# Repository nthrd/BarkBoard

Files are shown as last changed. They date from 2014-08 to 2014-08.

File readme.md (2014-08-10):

BarkBoard for BeagleBone Black
==============================

Overview
--------
The BarkBoard is concept for a DSP and modular amplifier cape for the BeagleBone and BeagleBone Black. Leveraging an digital signal processor, a high powered ADC/DAC, radio tuner and optional bluetooth audio module in addition to the digital audio output of the BeagleBone, the BarkBoard will makes any custom audio solution simple to build. A modular connector board will provide the ability to interface with a variety of audio systems, such as OEM car stereo plugs, musical instruments or home theater systems. Individual ready-made or custom amplifier boards will allow you to determine how much power you want to put into each channel depending on your application.

Form Factor
-----------

The BarkBoard is designed to fit inside a standard double-DIN enclosure used for many car-stereos. Add a GPS cape to this board and a car-navigation system is at your fingerprints. The modular connector board and amplifier boards are designed to be rear facing and are adaptable to a variety of audio systems. Some ideas include:
*  Custom Android or Linux Car-Stereo
*  Custom Audio player
*  Guitar amplifier with digital effects and the ability to mix other instruments.
*  Home Theater system

Digital Signal Processing
-------------------------

The power of the on board DSP combined with the ability to fully program the algorithms available on the board make the bark board a very versatile solution. Write your own algorithms or select from a variety of existing plugins to modify the digital audio signals as they flow from one source to another on the board, creating a custom sound tailored to your application. With the ability to load and configure software at boot or while running via the BeagleBoard's I2C, here are just a few ways you might utilize this chip.
Mix digital Audio Signals
*  Equalization
*  Tone Control
*  Bass Boost
*  Custom Effects
*  Custom Connector Board

The modular connector board can be used in many situations. Use a phono jack to plug in your guitar or 3D print a connector to mimic your OEM car stereo. The board will come with an one of the following (as an option):
Basic Audio connection: Speaker terminals for output and 2.5mm jacks for line in and mic in.
Home Theater: RCA jacks for all 6 audio output channels, S/PDIF in/out, 2.5mm jack for line in.
Protoboard: Positioned and labeled headers with a bunch of holes for prototyping your custom connection.
Custom Amplifier Boards

Each amplifier board is supplied with the differential analog output from the DAC, two control pins connected to an ATMEGA 328, which can be controlled via I2C from using the beagleboard a +12V supply and a +3.3V supply. One of the control pins on each board is connected to the 328's PWM pin and can be used as an analog control. The output pins connect straight through to the connector board. Off-the-shelf options for this board may include:
*  Protoboard: Positioned and labeled headers with a bunch of holes for prototyping your custom amplifier.
*  Pass-through Board: Pass the outputs of the DAC straight to the connection board.
*  1W/channel amplifier board
*  10W/channel amplifier board

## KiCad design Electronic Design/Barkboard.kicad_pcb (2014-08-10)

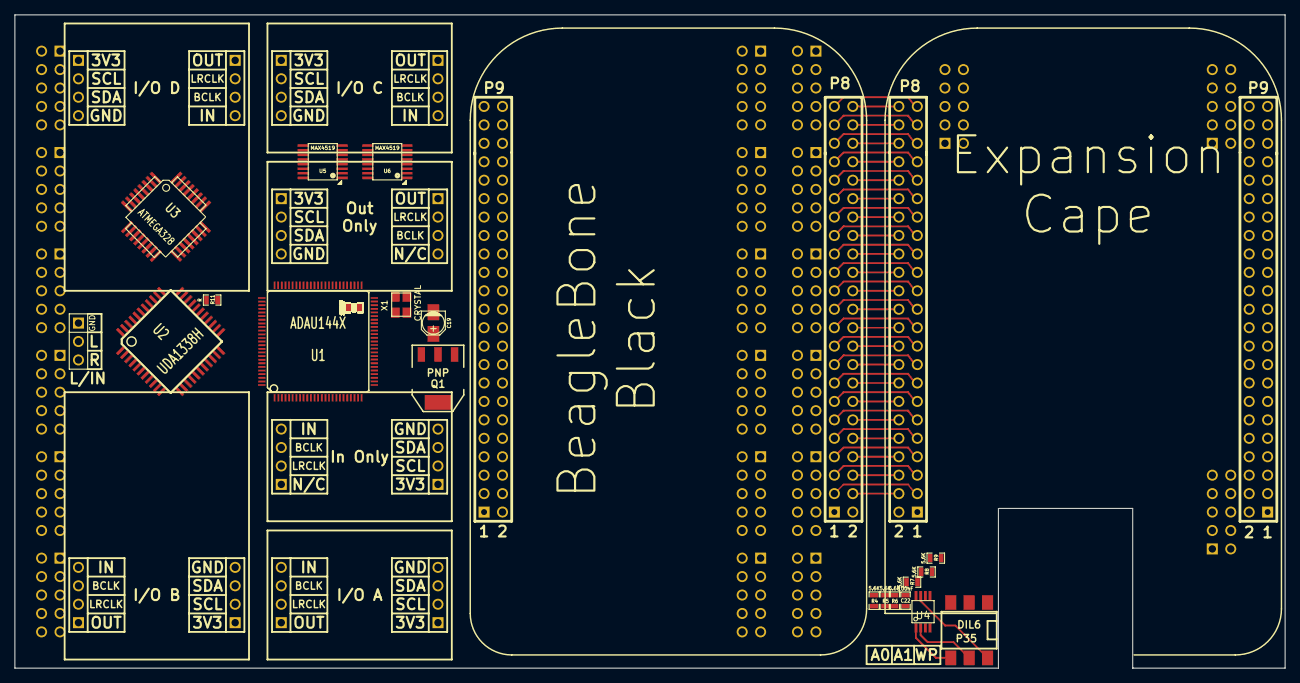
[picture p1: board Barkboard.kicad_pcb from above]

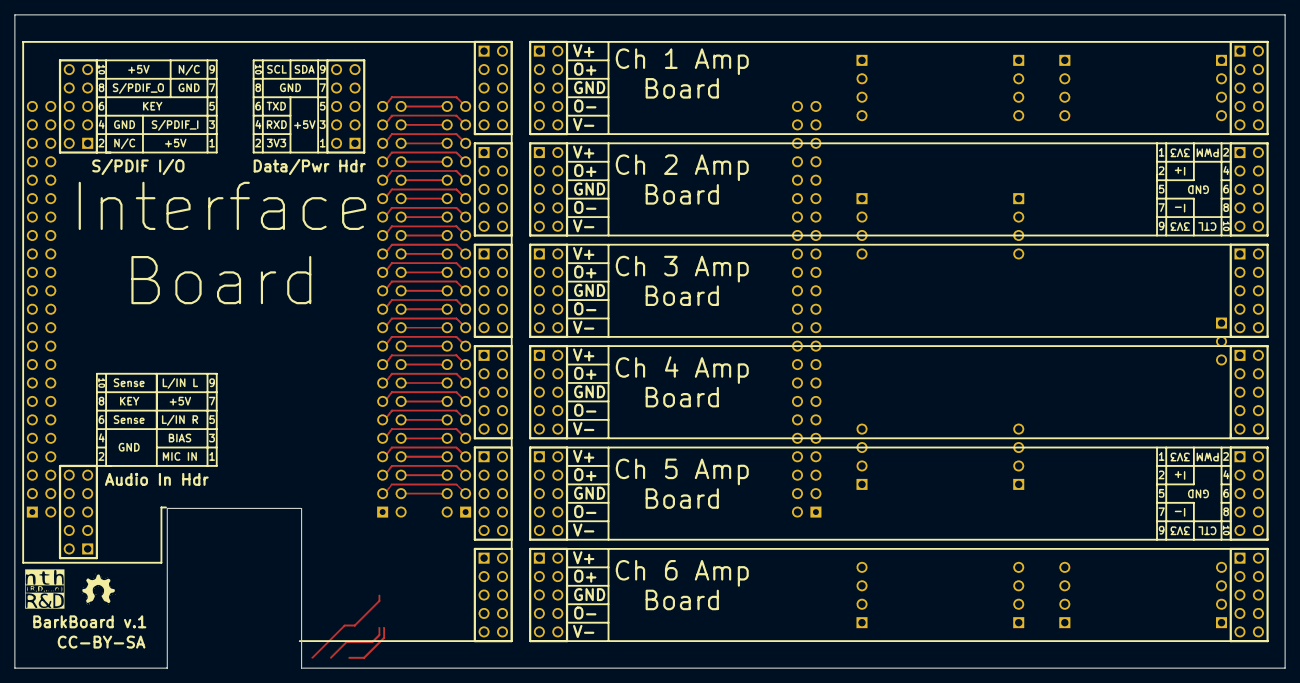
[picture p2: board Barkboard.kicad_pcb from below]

Board: 4 copper layers, 175.0 x 90.0 mm, 79 parts (21 on the bottom side), 197 nets.

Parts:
C1: 33nF; SM0603_Capa
C2: 1.8nF; SM0603_Capa
C3, C4, C5, C6, C7, C8, C9, C10, C11, C12, C13, C14, C15, C16, C17, C18, C22: 100nF; SM0603_Capa
C19: 10uF; c_elec_3x5.3
C20, C21: 22pF; SM0603_Capa
P1: Bone_P8; BONE_HDR_FLIP
P2: Bone_P9; BONE_HDR_FLIP
P3: Cape_P8; PIN_ARRAY_23X2
P4: Cape_P9; PIN_ARRAY_23X2
P5, P6, P7, P8, P9, P10, P11, P12, P13, P14, P15, P16, P21, P22, P23, P24, P25, P26, P36, P37, P38: CONN_5X2; PIN_ARRAY_5x2
P17: IODA; PIN_ARRAY_4x1
P18: IOPA; PIN_ARRAY_4x1
P19: IODB; PIN_ARRAY_4x1
P20: IOPB; PIN_ARRAY_4x1
P27: IODC; PIN_ARRAY_4x1
P28: IOPC; PIN_ARRAY_4x1
P29: IODD; PIN_ARRAY_4x1
P30: IOPD; PIN_ARRAY_4x1
P31: IP; PIN_ARRAY_4x1
P32: ID; PIN_ARRAY_4x1
P33: OP; PIN_ARRAY_4x1
P34: OD; PIN_ARRAY_4x1
P35: DIL6; 6DIPCMS
P39: CONN_3; PIN_ARRAY_3X1
Q1: PNP; SOT223
R1: 1.5K; SM0603_Resistor
R2: 10K; SM0603_Resistor
R3: 100; SM0603_Resistor
R4, R5, R6, R7, R8, R9: 5.6K; SM0603_Resistor
R11: R; SM0603_Resistor
U1: ADAU144X; TQFP_100
U2: UDA1338H; TQFP44
U3: ATMEGA328; TQFP32
U4: 24C256; SSOP8
U5, U6: MAX4519; qsop-16
X1: CRYSTAL; crystal_FA238-TSX3225

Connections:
3V3: C2.1, C3.1, C5.1, C6.1, C8.1, C10.1, C11.1, C13.1, C14.1, C16.1, C18.1, P18.1, P20.1, P21.1, P21.9, P22.1, P22.9, P23.1, P23.9, P24.1, P24.9, P25.1, P25.9, P26.1, P26.9, P28.1, P30.1, P31.1, P33.1, P38.2, Q1.1, R1.1, R11.1, U1.2, U1.14, U1.27, U1.39, U1.44, U1.49, U1.52, U1.63, U1.77, U1.89, U2.5, U2.9, U2.29, U2.37, U5.2, U5.14, U6.2, U6.14
+1.8V: C4.1, C7.1, C9.1, C12.1, C15.1, C17.1, C19.1, Q1.3, U1.25, U1.37, U1.50, U1.75, U1.87, U1.100
+5V: P2.5, P2.6, P4.5, P4.6, P36.1, P36.10, P37.7, P38.1, P38.3, P38.5
/AD1: U1.5, U2.13
/AD2: U1.8, U2.12
/ADBC: U1.9, U2.14
/ADLR: U1.10, U2.15
/ADV: U1.11, U2.16
/ADVBC: U1.12, U2.17
/ADVLR: U1.15, U2.18
/AD_RESET: U1.54, U3.23
/AT_RX: U3.30, U5.10, U6.4
/AT_TX: U3.31, U5.4, U6.10
/Amplifier and Interface Connectors/C1_CTL: P21.10, U3.32
/Amplifier and Interface Connectors/C1_I+: P21.3, U2.31
/Amplifier and Interface Connectors/C1_I-: P21.7, U2.32
/Amplifier and Interface Connectors/C1_O+: P5.3, P5.4, P11.3, P11.4
/Amplifier and Interface Connectors/C1_O-: P5.7, P5.8, P11.7, P11.8
/Amplifier and Interface Connectors/C1_PWM: P21.2, U3.1
/Amplifier and Interface Connectors/C1_V+: P5.1, P5.2, P11.1, P11.2
/Amplifier and Interface Connectors/C1_V-: P5.9, P5.10, P11.9, P11.10
/Amplifier and Interface Connectors/C2_CTL: P22.10, U3.2
/Amplifier and Interface Connectors/C2_I+: P22.3, U2.33
/Amplifier and Interface Connectors/C2_I-: P22.7, U2.34
/Amplifier and Interface Connectors/C2_O+: P6.3, P6.4, P12.3, P12.4
/Amplifier and Interface Connectors/C2_O-: P6.7, P6.8, P12.7, P12.8
/Amplifier and Interface Connectors/C2_PWM: P22.2, U3.9
/Amplifier and Interface Connectors/C2_V+: P6.1, P6.2, P12.1, P12.2
/Amplifier and Interface Connectors/C2_V-: P6.9, P6.10, P12.9, P12.10
/Amplifier and Interface Connectors/C3_CTL: P23.10, U3.11
/Amplifier and Interface Connectors/C3_I+: P23.3, U2.35
/Amplifier and Interface Connectors/C3_I-: P23.7, U2.36
/Amplifier and Interface Connectors/C3_O+: P7.3, P7.4, P13.3, P13.4
/Amplifier and Interface Connectors/C3_O-: P7.7, P7.8, P13.7, P13.8
/Amplifier and Interface Connectors/C3_PWM: P23.2, U3.10
/Amplifier and Interface Connectors/C3_V+: P7.1, P7.2, P13.1, P13.2
/Amplifier and Interface Connectors/C3_V-: P7.9, P7.10, P13.9, P13.10
/Amplifier and Interface Connectors/C4_CTL: P24.10, U3.12
/Amplifier and Interface Connectors/C4_I+: P24.3, U2.38
/Amplifier and Interface Connectors/C4_I-: P24.7, U2.39
/Amplifier and Interface Connectors/C4_O+: P8.3, P8.4, P14.3, P14.4
/Amplifier and Interface Connectors/C4_O-: P8.7, P8.8, P14.7, P14.8
/Amplifier and Interface Connectors/C4_PWM: P24.2, U3.13
/Amplifier and Interface Connectors/C4_V+: P8.1, P8.2, P14.1, P14.2
/Amplifier and Interface Connectors/C4_V-: P8.9, P8.10, P14.9, P14.10
/Amplifier and Interface Connectors/C5_CTL: P25.10, U3.16
/Amplifier and Interface Connectors/C5_I+: P25.3, U2.41
/Amplifier and Interface Connectors/C5_I-: P25.7, U2.42
/Amplifier and Interface Connectors/C5_O+: P9.3, P9.4, P15.3, P15.4
/Amplifier and Interface Connectors/C5_O-: P9.7, P9.8, P15.7, P15.8
/Amplifier and Interface Connectors/C5_PWM: P25.2, U3.14
/Amplifier and Interface Connectors/C5_V+: P9.1, P9.2, P15.1, P15.2
/Amplifier and Interface Connectors/C5_V-: P9.9, P9.10, P15.9, P15.10
/Amplifier and Interface Connectors/C6_CTL: P26.10, U3.17
/Amplifier and Interface Connectors/C6_I+: P26.3, U2.43
/Amplifier and Interface Connectors/C6_I-: P26.7, U2.44
/Amplifier and Interface Connectors/C6_O+: P10.3, P10.4, P16.3, P16.4
/Amplifier and Interface Connectors/C6_O-: P10.7, P10.8, P16.7, P16.8
/Amplifier and Interface Connectors/C6_PWM: P26.2, U3.15
/Amplifier and Interface Connectors/C6_V+: P10.1, P10.2, P16.1, P16.2
/Amplifier and Interface Connectors/C6_V-: P10.9, P10.10, P16.9, P16.10
/Amplifier and Interface Connectors/LineIn_L: P37.9, U2.6
/Amplifier and Interface Connectors/LineIn_R: P37.5, U2.8
/Amplifier and Interface Connectors/MIC: P37.1, U2.10
/Amplifier and Interface Connectors/SPDIF_IN: P36.3, U1.46
/Amplifier and Interface Connectors/SPDIF_OUT: P36.8, U1.47
/Amplifier and Interface Connectors/UART_RX: P38.4, U6.11
/Amplifier and Interface Connectors/UART_TX: P38.6, U5.11
/BeagleBone and Cape/3V3_exp: C22.1, P2.3, P2.4, P4.3, P4.4, R4.1, R5.1, R6.1, R7.1, R8.1, R9.1, U4.8
/BeagleBone and Cape/5V_SYS: P2.7, P2.8, P4.7, P4.8
/BeagleBone and Cape/AIN0: P2.39, P4.39
/BeagleBone and Cape/AIN1: P2.40, P4.40
/BeagleBone and Cape/AIN2: P2.37, P4.37
/BeagleBone and Cape/AIN3: P2.38, P4.38
/BeagleBone and Cape/AIN4: P2.33, P4.33
/BeagleBone and Cape/AIN5: P2.36, P4.36
/BeagleBone and Cape/AIN6: P2.35, P4.35
/BeagleBone and Cape/CLKOUT2: P2.41, P4.41
/BeagleBone and Cape/EHRPWM1A: P2.14, P4.14
/BeagleBone and Cape/EHRPWM1B: P2.16, P4.16
/BeagleBone and Cape/EHRPWM2A: P1.19, P3.19
/BeagleBone and Cape/EHRPWM2B: P1.13, P3.13
/BeagleBone and Cape/GNDA_ADC: P2.34, P4.34
/BeagleBone and Cape/GPIO0_7: P2.42, P4.42
/BeagleBone and Cape/GPIO0_26: P1.14, P3.14
/BeagleBone and Cape/GPIO1_0: P1.25, P3.25
/BeagleBone and Cape/GPIO1_1: P1.24, P3.24
/BeagleBone and Cape/GPIO1_2: P1.5, P3.5
/BeagleBone and Cape/GPIO1_3: P1.6, P3.6
/BeagleBone and Cape/GPIO1_4: P1.23, P3.23
/BeagleBone and Cape/GPIO1_5: P1.22, P3.22
/BeagleBone and Cape/GPIO1_6: P1.3, P3.3
/BeagleBone and Cape/GPIO1_7: P1.4, P3.4
/BeagleBone and Cape/GPIO1_12: P1.12, P3.12
/BeagleBone and Cape/GPIO1_13: P1.11, P3.11
/BeagleBone and Cape/GPIO1_14: P1.16, P3.16
/BeagleBone and Cape/GPIO1_15: P1.15, P3.15
/BeagleBone and Cape/GPIO1_16: P2.15, P4.15
/BeagleBone and Cape/GPIO1_17: P2.23, P4.23
/BeagleBone and Cape/GPIO1_27: P1.17, P3.17
/BeagleBone and Cape/GPIO1_28: P2.12, P4.12
/BeagleBone and Cape/GPIO1_29: P1.26, P3.26
/BeagleBone and Cape/GPIO1_30: P1.21, P3.21
/BeagleBone and Cape/GPIO1_31: P1.20, P3.20
/BeagleBone and Cape/GPIO2_1: P1.18, P3.18
/BeagleBone and Cape/GPIO2_6: P1.45, P3.45
/BeagleBone and Cape/GPIO2_7: P1.46, P3.46
/BeagleBone and Cape/GPIO2_8: P1.43, P3.43
/BeagleBone and Cape/GPIO2_9: P1.44, P3.44
/BeagleBone and Cape/GPIO2_10: P1.41, P3.41
/BeagleBone and Cape/GPIO2_11: P1.42, P3.42
/BeagleBone and Cape/GPIO2_12: P1.39, P3.39
/BeagleBone and Cape/GPIO2_13: P1.40, P3.40
/BeagleBone and Cape/GPIO2_22: P1.27, P3.27
/BeagleBone and Cape/GPIO2_23: P1.29, P3.29
/BeagleBone and Cape/GPIO2_24: P1.28, P3.28
/BeagleBone and Cape/GPIO2_25: P1.30, P3.30
/BeagleBone and Cape/GPIO3_19: P2.27, U1.90
/BeagleBone and Cape/GPIO3_21: P2.25, P4.25
/BeagleBone and Cape/ID_ADD0: P35.4, R4.2, U4.1
/BeagleBone and Cape/ID_ADD1: P35.5, R5.2, U4.2
/BeagleBone and Cape/ID_SCL: P2.19, P4.19, R8.2, U4.6
/BeagleBone and Cape/ID_SDA: P2.20, P4.20, R9.2, U4.5
/BeagleBone and Cape/PWR_BUT: P2.9, P4.9
/BeagleBone and Cape/SPI1_CS: P2.28, U1.84
/BeagleBone and Cape/SPI1_D0: P2.29, U1.86
/BeagleBone and Cape/SPI1_D1: P2.30, P4.30
/BeagleBone and Cape/SPI1_SCLK: P2.31, U1.85
/BeagleBone and Cape/SYS_RESETn: P2.10, P4.10
/BeagleBone and Cape/TIEMR5: P1.9, P3.9
/BeagleBone and Cape/TIMER4: P1.7, P3.7
/BeagleBone and Cape/TIMER6: P1.10, P3.10
/BeagleBone and Cape/TIMER7: P1.8, P3.8
/BeagleBone and Cape/UART1_RXD: P2.26, P4.26, U6.5
/BeagleBone and Cape/UART1_TXD: P2.24, P4.24, U5.5
/BeagleBone and Cape/UART2_RXD: P2.22, P4.22
/BeagleBone and Cape/UART2_TXD: P2.21, P4.21
/BeagleBone and Cape/UART3_CTSN: P1.36, P3.36
/BeagleBone and Cape/UART3_RTSN: P1.34, P3.34
/BeagleBone and Cape/UART4_CTSN: P1.35, P3.35
/BeagleBone and Cape/UART4_RTSN: P1.33, P3.33
/BeagleBone and Cape/UART4_RXD: P2.11, P4.11
/BeagleBone and Cape/UART4_TXD: P2.13, P4.13
/BeagleBone and Cape/UART5_CTSN: P1.31, P3.31
/BeagleBone and Cape/UART5_RTSN: P1.32, P3.32
/BeagleBone and Cape/UART5_RXD: P1.38, P3.38
/BeagleBone and Cape/UART5_TXD: P1.37, P3.37
/BeagleBone and Cape/VDD_ADC: P2.32, P4.32
/BeagleBone and Cape/WP: P35.6, R7.2, U4.7
/DA12: U1.69, U2.25
/DA34: U1.66, U2.26
/DA56: U1.61, U2.27
/DABC: U1.64, U2.24
/DALR: U1.65, U2.23
/IBC: P32.3, U1.3
/II: P32.4, U1.99
/ILR: P32.2, U1.4
/IOABC: P17.3, U1.96
/IOAI: P17.4, U1.95
/IOALR: P17.2, U1.97
/IOAO: P17.1, U1.98
/IOBBC: P19.3, U1.92
/IOBI: P19.4, U1.91
/IOBLR: P19.2, U1.93
/IOBO: P19.1, U1.94
/IOCBC: P27.3, U1.74
/IOCI: P27.4, U1.73
/IOCLR: P27.2, U1.78
/IOCO: P27.1, U1.79
/IODBC: P29.3, U1.81
/IODI: P29.4, U1.80
/IODLR: P29.2, U1.82
/IODO: P29.1, U1.83
/MP8: U1.19, U5.1, U6.1
/MP9: U1.18, U5.16, U6.16
/MP10: U1.17, U3.29
/MP11: U1.16, U2.20
/MSTR_CLK: U1.53, U2.19
/OBC: P34.3, U1.70
/OLR: P34.2, U1.71
/OO: P34.1, U1.72
/PFILT: C1.2, C2.2, U1.43
/VDRIVE: Q1.2, U1.40
/XI: C20.1, U1.42, X1.2
/XO1: R3.1, U1.41
/XO2: C21.1, R3.2, X1.1
GND: C3.2, C4.2, C5.2, C6.2, C7.2, C8.2, C9.2, C10.2, C11.2, C12.2, C13.2, C14.2, C15.2, C16.2, C17.2, C18.2, C19.2, C20.2, C21.2, C22.2, P1.1, P1.2, P2.1, P2.2, P2.43, P2.44, P2.45, P2.46, P3.1, P3.2, P4.1, P4.2, P4.43, P4.44, P4.45, P4.46, P5.5, P5.6, P6.5, P6.6, P7.5, P7.6, P8.5, P8.6, P9.5, P9.6, P10.5, P10.6, P11.5, P11.6, P12.5, P12.6, P13.5, P13.6, P14.5, P14.6, P15.5, P15.6, P16.5, P16.6, P18.4, P20.4, P21.4, P21.5, P21.6, P21.8, P22.4, P22.5, P22.6, P22.8, P23.4, P23.5, P23.6, P23.8, P24.4, P24.5, P24.6, P24.8, P25.4, P25.5, P25.6, P25.8, P26.4, P26.5, P26.6, P26.8, P28.4, P30.4, P31.4, P33.4, P35.1, P35.2, P35.3, P36.4, P36.7, P37.2, P37.4, P38.7, P38.8, P39.1, R2.1, U1.1, U1.13, U1.20, U1.21, U1.24, U1.26, U1.28, U1.38, U1.45, U1.48, U1.51, U1.62, U1.76, U1.88, U2.3, U2.7, U2.11, U2.28, U2.40, U3.3, U3.5, U3.21, U4.4, U5.3, U5.13, U6.3, U6.13
unnamed: R2.2, U1.31
unnamed: C1.1, R1.2
unnamed: R11.2, U2.30
unnamed: P39.2, U2.2
unnamed: P39.3, U2.4
unnamed: U5.6, U5.9
unnamed: U6.6, U6.9
unnamed: R6.2, U4.3
SCL: P2.17, P4.17, P18.2, P20.2, P28.2, P30.2, P31.2, P33.2, P38.10, U1.22, U2.21, U3.28
SDA: P2.18, P4.18, P18.3, P20.3, P28.3, P30.3, P31.3, P33.3, P38.9, U1.23, U2.22, U3.27

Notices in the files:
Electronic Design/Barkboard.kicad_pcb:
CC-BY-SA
